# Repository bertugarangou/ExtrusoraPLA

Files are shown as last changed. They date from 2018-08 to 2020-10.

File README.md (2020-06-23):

# Extrusora PLA
Extrusora de plàstic PLA per produir filament reciclat per Impressores 3D.
Accés al projecte limitat. Veieu "[llicència](LICENSE.md)" o a través de [contacte](mailto:albertgarangou@gmail.com).

## Referències
* [Arduino](https://www.arduino.cc/) - Software
* [Arduino LiquidCrystal Library](https://www.arduino.cc/en/Reference/LiquidCrystal) - LLibreria d'Arduino per LCD.
* [Arduino Tasker Library](https://github.com/joysfera/arduino-tasker) - Llibreria d'Arduino per l'ús multi-tasca.
* Possiblament més referències poden ser incloses, en futur o actuals.

## Autors
* **Albert Garangou Culebras** - *Autor principal del projecte*

## Llicència
**Tots els drets reservats, Albert Garangou Culebras.**
Podeu trobar una còpia de la llicència a [LICENSE.md](LICENSE.md) i més detalls sobre el que és permés.

## Reconeixaments
* *Tutor del Treball de Recerca* - **Jordi Fanals Oriol**

## Contacte
Podeu contactar al correu [albertgarangou@gmail.com](mailto:albertgarangou@gmail.com).
També per missetjaria de Github si teniu un perfil.

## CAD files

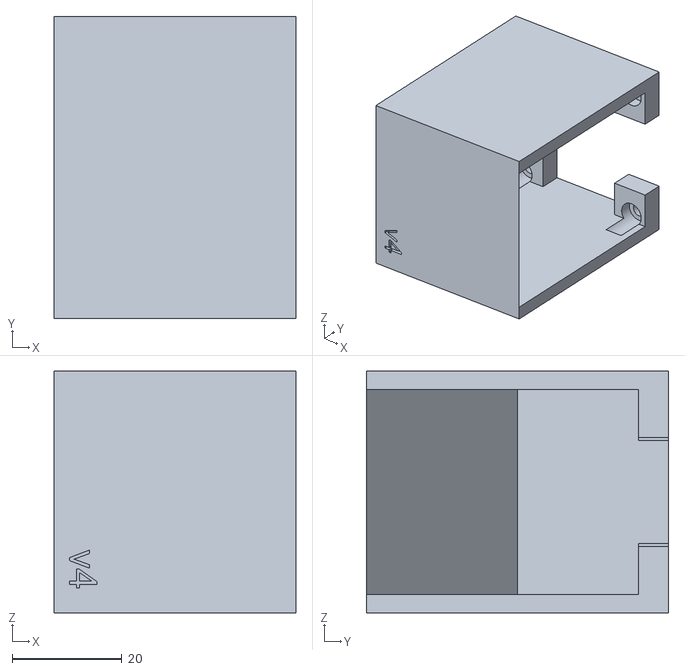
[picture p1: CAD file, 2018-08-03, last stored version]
Parts3D/Parts_STL_per_imprimir/Cos Refrigerador v4.stl
44.0 x 55.0 x 44.0

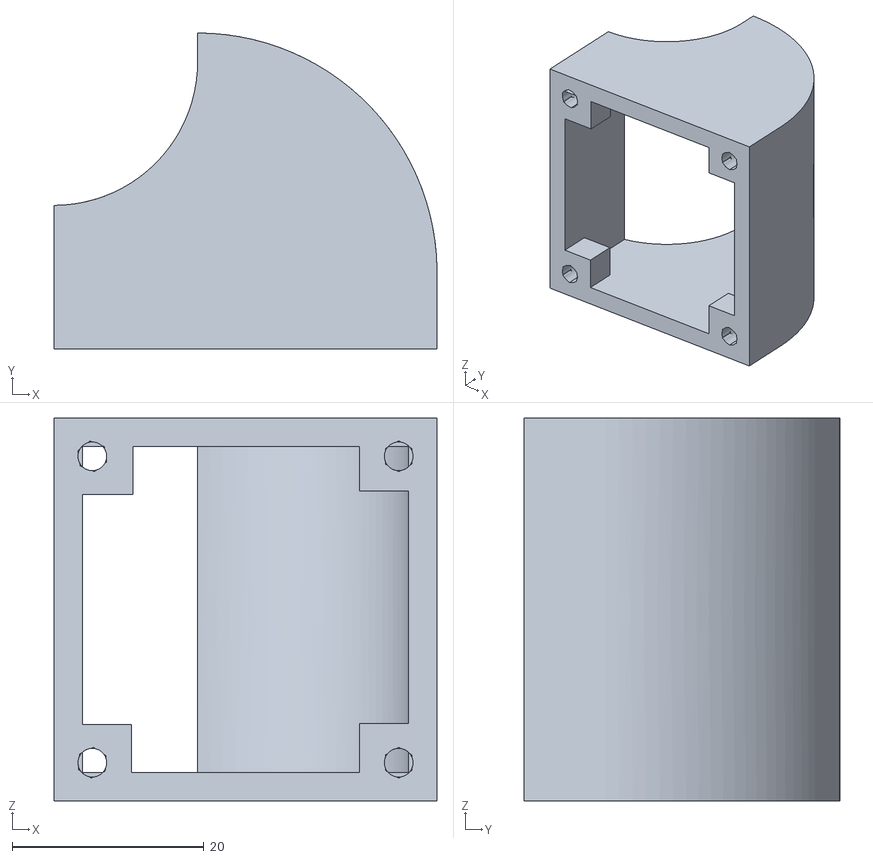
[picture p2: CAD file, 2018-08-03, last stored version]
Parts3D/Parts_STL_per_imprimir/Boca Refrigerador v2.stl
40.0 x 33.0 x 40.0

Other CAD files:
Esquemes/Ensamblatge Broca-Eix motor.dwg
Parts/Esquemes/0. Base/Estructura base.dwg
Parts/Esquemes/1. Extrusora/suport motor-1.dwg
Esquemes/suport motor-1.dwg
Parts/Esquemes/1. Extrusora/tremuja.ipt
Parts/Models/0. Base/Estructura base.ipt
Parts/Models/1. Ventiladors/Ventilador bobina - boca.ipt
Parts/Models/1. Ventiladors/Ventilador bobina - suport.ipt
Parts/Models/1. Ventiladors/Ventilador controladores - boca.ipt
Parts/Models/1. Ventiladors/Ventilador controladores - suport.ipt
Parts/Models/1. Ventiladors/Ventilador filament - boca.ipt
Parts/Models/1. Ventiladors/Ventilador filament - cosPETIT.ipt
Parts/Models/1. Ventiladors/Ventilador tub - cos.ipt
Parts/Models/1. Ventiladors/Ventilador tub - guies.ipt
Parts/Models/1. Ventiladors/ventilador emergència inferior.ipt
Parts/Models/1. Ventiladors/ventilador emergència superior.ipt
Parts/Models/2. Extrusora/Motor extrusora - suport.ipt
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

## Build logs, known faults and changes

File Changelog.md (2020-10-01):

# Historial de versions

### Com funciona:
### Versió [NUMERO] (Data) - *CodeName*
 ### <No Funcional>

 #### Millores

  * Descripció
  * Descripció
      * Contingut

 #### Correccions
  * Descripció

 #### Errors coneguts
  * Descripció

 #### Més informació
  * "Commits"

---
---
---

## Versió 1 (15/10/2018) - *Inicial*

 ### Errors coneguts
  * El sensor IR detecta el fil per cualpa d'alguns llums d'habitacions. 
---
## Versió 1.1 (16/10/2018)
 ### Millores
  * El sensor IR detecta correctament el filament amb un protector.
 ---
 ## Versió 1.2 (22/11/2018)
  ### Millores
   * Adaptació per entrega TdR
 ---
  ## Versió 1.3 (12/02/2019)
   ### Millores
   * Rectificació llicència
 ---
  ## Versió 1.3.1 (01/06/2019)
   ### Canvis
   * Restrinció de l'accés al projecte amb efecte retroactiu. Ja no es permet l'accés públic, només sota demanda.
 ---
  ## Versió 1.3.1 (01/10/2020)
   ### Canvis
   * Modificació de l'estructura de llicència i usos del projecte per arxivar-lo indefinidament.

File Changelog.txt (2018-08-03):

# Historial de versions

### Com funciona?

 ## Versió [NUMERO] - *CodeName*
 
  * Canvi 1
  * Canvi 2
  * ...

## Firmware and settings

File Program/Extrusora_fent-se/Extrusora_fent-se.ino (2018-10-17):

/*
  Extrusora de PLA controlada per Arduino Mega 2560.

  Projecte:
  - https://github.com/bertugarangou/ExtrusoraPLA
  - Extrusora feta per Albert Garangou,
    com a Treball de Recerca a 2n de Batxillerat,
    curs 2018/2019, tutor: Jordi Fanals Oriol,
    codi amb Arduino IDE.
  - Tots els drets reservats 2019 Albert Garangou Culebras (albertgarangou@gmail.com).
    Aquest codi està llicenciat amb base a la Creative "Commons Attribution-NonCommercial-NoDerivatives 4.0 International License".
    Altres regles i mesures pròpies sobreescriuen i modifiquen aquesta llicència són presents, consulta el web origen per a més informació.

*/
/*+++++++++++++Llibreries++++++++++++++*/
#include <max6675.h>
MAX6675 tempSensorResistors(11, 12, 13);
MAX6675 tempSensorEnd(8, 9, 10);

#include <Wire.h>

#include <LiquidCrystal_I2C.h>
LiquidCrystal_I2C lcd(0x27, 16, 2); //PINS SDA i SCL lcd

/*+++++++++++++Llibreries++++++++++++++*/
/*++Declaració variables i constants+++*/
int const lcdUpdateFrequency = 250;  //1000-1500-x
int const tempReaderFrequency = 1000; //1000-1500-x
int const heaterFrequency = 0; //0 (instantari)-500-1000-x

int const INTFanFil = 6;
int const INTFanTube = 7;
int const relayFanFil = 52;
int const relayFanTube = 50;
int const STOPBtn = 30;
int const brunzidor = 51;
int const extruderStep = 25;
int const extruderDir = 26;
int const extruderEn = 28;
int const coilStep = 24;
int const coilDir = 27;
int const coilEn = 29;
int const filamentDetector = 36;
int const INTHeat = 53;
int const INTExtruder = 2;
int const INTExtruderRev = 3;
int const INTCoil = 4;
int const INTCoilRev = 5;
int const INTHeater = 49;
int const relayResistors = 32;

bool error = false;
bool canExtrude = false;
bool canCoil = false;

bool extrudingFwd = false;
bool extrudingRev = false;
bool coilingFwd = false;
bool coilingRev = false;

bool heatingPause = false;
bool heating = false;

bool canCoilByFilamentDetector = false;

int tempToShow;
float tempRest = 0.0;
float currentTempResistors = 0.0;
float currentTempEnd = 0.0;

float desiredTemp;
float desiredTempEnd;
float desiredTempResistors;

float tempResistors1 = 0.0;
float tempResistors2 = 0.0;
float tempResistors3 = 0.0;
float tempEnd1 = 0.0;
float tempEnd2 = 0.0;
float tempEnd3 = 0.0;
float finalTempEnd = 0.0;
float finalTempResistors = 0.0;

int const slowTempRange = 5;  

int tempResistorsRest;
int tempEndRest;

unsigned long ultimMillis_LCDMain = 0UL;
unsigned long ultimMillis_extruderStart = 0UL;
unsigned long ultimMillis_extruderStop = 0UL;
unsigned long ultimMillis_coilStart = 0UL;
unsigned long ultimMillis_coilStop = 0UL;
unsigned long ultimMillis_tempReader = 0UL;
unsigned long ultimMillis_heaterMain = 0UL;

int const extruderNEINSpeed = 6;
int const coilNEINSpeed = 20;

byte downArrow[8] = {
  B00100,
  B00100,
  B00100,
  B00100,
  B00100,
  B10101,
  B01110,
  B00100
};

byte upArrow[8] = {
  B00100,
  B01110,
  B10101,
  B00100,
  B00100,
  B00100,
  B00100,
  B00100
};

byte cross[8] = {
  B00000,
  B10001,
  B01010,
  B00100,
  B01010,
  B10001,
  B00000,
  B00000
};

byte check[8] = {
  B00000,
  B00000,
  B00001,
  B00010,
  B10100,
  B01000,
  B00000,
  B00000
};

byte rev[8] = {
  B00010,
  B00110,
  B01110,
  B11110,
  B01110,
  B00110,
  B00010,
  B00000
};

byte pause[8] = {
  B00000,
  B01010,
  B01010,
  B01010,
  B01010,
  B01010,
  B00000,
  B00000
};

/*++Declaració variables i constants+++*/
/*+++++++++++Declaracio funcions+++++++++++*/
void lcdController();
void fansController();
void extruderController();
void coilController();
void filamentDetectorFunction();
void heater();
void tempRead();
void errorProcedure();
void quickTempRead();
/*+++++++++++Declaracio funcions+++++++++++*/

void setup(){
  Serial.begin(9600); //inicia la depuració
  lcd.init();
  lcd.backlight();
  lcd.createChar(1, downArrow);
  lcd.createChar(2, upArrow);
  lcd.createChar(3, cross);
  lcd.createChar(4, check);
  lcd.createChar(5, rev);
  lcd.createChar(6, pause);
  
  lcd.clear();
  pinMode(INTFanFil, INPUT);
  pinMode(INTFanTube, INPUT);
  pinMode(STOPBtn, INPUT);
  pinMode(relayFanFil, OUTPUT);
  pinMode(relayFanTube, OUTPUT);
  pinMode(brunzidor, OUTPUT);
  pinMode(extruderStep, OUTPUT);
  pinMode(extruderDir, OUTPUT);
  pinMode(extruderEn, OUTPUT);
  pinMode(coilStep, OUTPUT);
  pinMode(coilDir, OUTPUT);
  pinMode(coilEn, OUTPUT);
  pinMode(filamentDetector, INPUT);
  pinMode(INTExtruder, INPUT);
  pinMode(INTExtruderRev, INPUT);
  pinMode(INTCoil, INPUT);
  pinMode(INTCoilRev, INPUT);
  pinMode(INTHeater, INPUT);
  pinMode(relayResistors, OUTPUT);
  digitalWrite(relayResistors, LOW);
}

void loop(){
 if(digitalRead(STOPBtn) == 0 || error == true){
  digitalWrite(brunzidor, HIGH);
  Serial.println("*****************************************");
  Serial.print("*   STOP");
  Serial.println(", entrant en mode emergència!   *");
  Serial.println("*                                       *");
  Serial.println("* NO DESCONECTAR FINS QUE ESTIGUI FRED! *");
  Serial.println("*****************************************");
  lcd.clear();
  lcd.print("!NO DESCONECTAR!");
  lcd.setCursor(9,1);
  lcd.print("ALERTA!");
  errorProcedure();
  while(true){//bucle infinit
  digitalWrite(brunzidor, LOW);
  lcd.noBacklight();
  quickTempRead();
  digitalWrite(brunzidor, HIGH);
  lcd.setCursor(0,1);
  lcd.print((int) finalTempResistors);
  lcd.print(char(223));
  lcd.print("/");
  lcd.print((int) finalTempEnd);
  lcd.print(char(223));
  lcd.backlight();
  delay(2000);
  }
 }
  else{ //funcionament estandart del programa (aka no hi ha cap error)
    lcdController();
    filamentDetectorFunction();
    fansController();
    tempRead();
    heater();
    extruderController();
    coilController();
    
  }
} //end

/*+++++++++++Definició funicons++++++++++++*/
void extruderController(){
  if (digitalRead(INTExtruder) == LOW && digitalRead(INTExtruderRev) == HIGH){//activat
    if(tempToShow > 169 && tempRest > -10){
      canCoil = true;
      if(millis() - ultimMillis_extruderStart >= extruderNEINSpeed){
        extrudingFwd = true;
        extrudingRev = false;
        digitalWrite(extruderStep, HIGH);
      if(millis() - ultimMillis_extruderStop >= extruderNEINSpeed){
        digitalWrite(extruderStep, LOW);
        ultimMillis_extruderStop = millis();
        ultimMillis_extruderStart = millis();
        }
      }
    }
  }
  else if(digitalRead(INTExtruder) == LOW && digitalRead(INTExtruderRev) == LOW){//invertit
    if(tempToShow > 169 && tempRest > -10){
      canCoil = false;
      if(millis() - ultimMillis_extruderStart >= extruderNEINSpeed){
        extrudingRev = true;
        extrudingFwd = false;
        digitalWrite(extruderDir, HIGH);
        digitalWrite(extruderStep, HIGH);
      if(millis() - ultimMillis_extruderStop >= extruderNEINSpeed){
        digitalWrite(extruderStep, LOW);
        digitalWrite(extruderDir, LOW);
        ultimMillis_extruderStop = millis();
        ultimMillis_extruderStart = millis();
        }
      }
    }
  }
  else{ //desactivat
    extrudingFwd = false;
    extrudingRev = false;
    canCoil = false;
  }
}

void coilController(){
  if (digitalRead(INTCoil) == LOW && digitalRead(INTCoilRev) == LOW){ // tots dos activats
    if(millis() - ultimMillis_coilStart >= coilNEINSpeed){
      coilingFwd = false;
      coilingRev = true;
      digitalWrite(coilStep, HIGH);
    if(millis() - ultimMillis_coilStop >= coilNEINSpeed){
      digitalWrite(coilStep, LOW);
      ultimMillis_coilStop = millis();
      ultimMillis_coilStart = millis();
      }
    }
  }
  else if(digitalRead(INTCoil) == LOW && digitalRead(INTCoilRev) == HIGH && canCoilByFilamentDetector == true){ // sense invertir direcció
    if(millis() - ultimMillis_coilStart >= coilNEINSpeed){
      coilingFwd = true;
      coilingRev = false;
      digitalWrite(coilDir, HIGH);
      digitalWrite(coilStep, HIGH);
      if(millis() - ultimMillis_coilStop >= coilNEINSpeed){
        digitalWrite(coilStep, LOW);
        digitalWrite(coilDir, LOW);
        ultimMillis_coilStop = millis();
        ultimMillis_coilStart = millis();
      }
    }
  }
  else{
    digitalWrite(coilStep, HIGH);
    coilingFwd = false;
    coilingRev = false;
  }
}

void fansController(){
  if(digitalRead(INTFanFil) == LOW){ //quan s'activa l'interruptor adequat
    digitalWrite(relayFanFil, LOW); //activar relé ventilador
    //Serial.println("Ventilador: Filament **ON**");
  }
  else{ //sinó
    digitalWrite(relayFanFil, HIGH); //desactiva'l
    //Serial.println("Ventilador: Filament **OFF**");
  }
    
  if(digitalRead(INTFanTube) == LOW){  //si s'activa l'interruptor adequat
    digitalWrite(relayFanTube, LOW);  //activa el relé del ventilador
    //Serial.println("Ventilador: Extrusora **ON**");
  }
  else{ //sinó
    digitalWrite(relayFanTube, HIGH);  //desactiva'l
    //Serial.println("Ventilador: Extrusora **OFF**");
  }
}

void lcdController(){
  if(millis() - ultimMillis_LCDMain >= lcdUpdateFrequency){
    lcd.setCursor(0,0);
    lcd.print((int) tempToShow);
    lcd.print("/");
    lcd.print((int) desiredTemp);
    lcd.print(char(223));
    lcd.print("  ");
      
    if(canExtrude == true){ //estat general
      lcd.setCursor(10,0);
      lcd.print("ACTIVAT");
    }
    else if(canExtrude == false && heating == true){
      lcd.setCursor(10,0);
      lcd.print("ESPERA");
    }
    else{
      lcd.setCursor(10, 0);
      lcd.print(" PAUSA");
    }

    if(extrudingFwd == true){ //estat extrusor
      lcd.setCursor(0,1);
      lcd.print("E:");
      lcd.write(4);
      lcd.print(" ");
    }
    else if(extrudingRev == true){
      lcd.setCursor(0,1);
      lcd.print("E:");
      lcd.write(5);
      lcd.write(5);
    }
    else{
      lcd.setCursor(0,1);
      lcd.print("E:");
      lcd.write(3);
      lcd.print(" ");
    }
    
    if(coilingFwd == true){  //estat bobina
      lcd.setCursor(11,1);
      lcd.print("B:");
      lcd.write(4);
      lcd.print(" ");
    }
    else if(coilingRev == true){
      lcd.setCursor(11,1);
      lcd.print("B:");
      lcd.write(5);
      lcd.write(5);
    }
     else{
      lcd.setCursor(11,1);
      lcd.print("B:");
      lcd.write(3);
      lcd.print(" ");
    }

    if(heating == true && heatingPause == false){  //estat heating
      lcd.setCursor(6,1);
      lcd.print("H:");
      lcd.write(4);
    }
    else if(heating == true && heatingPause == true){
      lcd.setCursor(6,1);
      lcd.print("H:");
      lcd.write(6);
    }
    else{
      lcd.setCursor(6,1);
      lcd.print("H:");
      lcd.write(3);
    }

    
      if(coilingFwd == true){
      lcd.setCursor(15,1);
      lcd.write(2);
      }
      else if(coilingRev == true){
      lcd.setCursor(15,1);
      lcd.write(1);
      }
    else{
      lcd.setCursor(15,1);
      lcd.print(" ");
      }
      
    ultimMillis_LCDMain = millis();
  }
}

void filamentDetectorFunction(){
  if(extrudingFwd == true){
    if(digitalRead(filamentDetector) == LOW){
      canCoilByFilamentDetector = true;
    }
    else{
      canCoilByFilamentDetector = false;
    }
  }
}

void heater(){
  if(digitalRead(INTHeater) == LOW){
    desiredTemp = 175;
    desiredTempResistors = 190;
    desiredTempEnd = 165;
    
    //if(millis() - ultimMillis_heaterMain >= heaterFrequency){
    tempRest = desiredTemp - tempToShow;
      if(tempToShow > 0 && tempRest > 1){  //escalfant de lluny
        digitalWrite(relayResistors, HIGH);
        heating = true;
        heatingPause = false;
      }
      else if(tempRest <= -2){  //massa alta
        digitalWrite(relayResistors, LOW);
        heating = true;
        heatingPause = true;
        digitalWrite(relayFanTube, LOW);
      }
      else if(tempToShow >0 && tempRest <= 1 && tempRest > -3){ // pausant temperatura està ok
        digitalWrite(relayResistors, LOW);
        heatingPause = true;
        heating = true;
      }
      else{ //no escalfa
        digitalWrite(relayResistors, LOW);
        heating = false;
        heatingPause = false;
      }
    //}
  }
  else if (digitalRead(INTHeater) == HIGH){
    desiredTempEnd = 0;
    desiredTempResistors = 0;
    desiredTemp = 0;
    digitalWrite(relayResistors, LOW);
    heating = false;
  }
}

void errorProcedure(){
  digitalWrite(relayFanFil, LOW);
  digitalWrite(relayFanTube, LOW);
  digitalWrite(extruderStep, HIGH);
  digitalWrite(coilStep, LOW);
  digitalWrite(relayResistors, LOW);
  //desiredTempAutoSetterVariableIDon'tKnowTheName = 0;
}

void quickTempRead(){
  tempEnd1 = tempSensorEnd.readCelsius();
  tempResistors1 = tempSensorResistors.readCelsius();
  delay(500);
  tempEnd2 = tempSensorEnd.readCelsius();
  tempResistors2 = tempSensorResistors.readCelsius();
  delay(500);
  tempEnd3 = tempSensorEnd.readCelsius();
  tempResistors3 = tempSensorResistors.readCelsius();
  finalTempEnd = (tempEnd1 + tempEnd2 + tempEnd3) / 3;
  finalTempResistors = (tempResistors1 + tempResistors2 + tempResistors3) / 3;
  
}

void tempRead(){
  if(millis() - ultimMillis_tempReader >= tempReaderFrequency){
    currentTempEnd = tempSensorEnd.readCelsius();
    currentTempResistors = tempSensorResistors.readCelsius();
    //Serial.println(currentTempEnd);
    //Serial.println(currentTempResistors);


    tempToShow = (currentTempEnd * 70 + currentTempResistors * 30) / 100;
    //Serial.println(tempToShow);
    //Serial.println("-------------");
    ultimMillis_tempReader = millis();
  }
  //heat suficient --> canExtrude = true
}
/*+++++++++++Definició funicons++++++++++++*/

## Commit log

2018-08-03 Uploaded 3D parts: old-acoplament, boca-refrigerador and cos-refrigerador
    [Boca Refrigerador v2.f3d, Boca Refrigerador v2.stl, Cos Refrigerador v4.f3d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]
2018-08-03 added 3d files and schemes
    [Boca Refrigerador v2.f3d, Boca Refrigerador v2.stl, Cos Refrigerador v4.f3d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]
2018-08-07 Added new 3d models and parts
    [Ensamblatge Broca-Eix motor.dwg, detector curvament fil.ipt, suport motor-1.dwg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]
2018-08-07 Added fritzing project
    [extruder.fzz]
2018-08-07 Updated fritzing comments
    [extruder.fzz]
2018-08-07 program moved to subfolder for direct use on Arduino IDE
2018-08-07 edited and reverted
    [extruder.fzz]
2018-08-07 Rewrote to use Stepper library
    No backward movement was done propperly so Arduino's library "Stepper" was added to do this frustrating painful little job
2018-08-07 Rewrote code to use stepper library
2018-08-08 Replaced L928n with tb6600
    [extruder.fzz]
2018-08-09 Added readTemp() function
    Added readTemp() which consists on reading the temp from a NTC, converting raw data to C and K degrees. It has benn used millis() to update those values to prevent stopping the entire code with delay()
    [Extrusora.ino]
2018-08-09 Don't know what has changed
    Scared to delete that...
    [extruder.fzz]
2018-08-13 added support for multiple fan switches
2018-08-13 improved Serial.print communications on switches
2018-08-13 added support for 2 motors and directional movement
2018-08-13 added missing comments 1/2
    [Extrusora.ino]
2018-08-13 see description for changes
    -replaced doStop() with automatic processes with checks
    -removed callerror() function (will be recovered later)
    -added heat procedures with PI (proportional and integrative)
    [Extrusora.ino]
2018-08-13 Added checks on heater's switch
2018-08-14 corrected diadoe polarization
    [extruder.fzz]
2018-08-14 Added lcd
    [extruder.fzz]
2018-08-17 Added up to date 3d parts
    [Bobinatge - eix bobina.ipt, Bobinatge - suport lateral.ipt, Bobinatge - suport motor.ipt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]
2018-08-18 updated 3d parts
    [Bobinatge - acoplament eix.ipt, Bobinatge - eix bobina.0011.ipt, Bobinatge - eix bobina.ipt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]
2018-08-18 support custom motor speed
2018-08-18 added new part
    [Caixa control - estructura.0020.ipt, Caixa control - estructura.ipt, Suport - pantalla i potenciometre.ipt]
2018-08-18 improved walls and fan holes
    [Suport - pantalla i potenciometre.ipt]
2018-08-19 various updates
    [Bobinatge - acoplament eix.ipt, Bobinatge - eix bobina.0011.ipt]
2018-08-19 improved coil axis radius
    [Bobinatge - eix bobina.ipt, Estructura base.0008.ipt]
2018-08-23 modified parts
    [Bobinatge - eix bobina.0013.ipt, Bobinatge - eix bobina.ipt, Ventilador controladores - suport.0008.ipt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]
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2018-08-23 updated with new power circuit
    [extruder.fzz]
2018-08-23 updated parts
    [Relé - columnes tapa.ipt, Relé - columnes.ipt, Suport - pantalla i potenciometre tapa.ipt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]
2018-08-27 updated power circuit
    [extruder.fzz]
2018-08-29 modified & added new parts
    [Bobinatge - eix bobina.0013.ipt, Caixa control - tapa.ipt, Detector fil - suport.ipt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]
2018-08-31 added new components
    [Caixa control - tapa.ipt, Pantalla - botó encoder.ipt, Pantalla - cos.ipt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]
2018-09-12 updated & added parts
    [Base auxiliar - encaix estructura.ipt, Base auxiliar - esquadra.ipt, Bobinatge - suport motor.ipt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]
2018-09-12 moved old parts into different folder
    [Bobinatge - acoplament eix.ipt, Ventilador filament - cos.ipt]
2018-09-22 added design
    [tremuja.dwg]
2018-09-22 solved incorrect route
    [extruder.fzz]
2018-09-22 added lcd i2c support
2018-09-30 added buzzer and power expander for lcd
    [extruder.fzz]
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2018-10-01 motors funcionals (ara si)
2018-10-01 actualització de velocitats dels motors
2018-10-01 neteja de codi per finalitzar els motors
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2018-10-03 lectura de temperatura funcional
2018-10-03 varies millores
    * sistema de seguretat millorat
    *nous caràcters de la pantalla (personalitzats) per indicar si el filament està sent bobinat o no
2018-10-03 valors d'actualització de pantalla i de lectura de temperatura reduits
2018-10-04 varies millores
    *nous caràcters per la lcd
    *arregalt els estats mostrats a la pantalla
    *sistema bàsic per escalfar
    *neteja de variables obsolertes
2018-10-04 llicència actualitzada amb les noves regles
2018-10-04 caràcters i sistema de senyal per l'escalfament funcionals
    [Bobinatge - eix bobina.ipt]
2018-10-04 correcció d'altura
    [Bobinatge - eix bobina.ipt]
2018-10-07 nou test per comprovar el relé d'estat sòlid sense perill delectrocució
2018-10-08 Revert "Update Program/Extrusora_fent-se/Extrusora_fent-se.ino"
    This reverts commit 7af50d72c9f8ea57fbfb48b0b4d528f124a5b9a6.
    [Extrusora_fent-se.ino]
2018-10-08 Revert "Revert "Update Program/Extrusora_fent-se/Extrusora_fent-se.ino""
    This reverts commit b195f3a1daab2889d0247883903246308dd127db.
    [Extrusora_fent-se.ino]
2018-10-09 reistències de calor funcionals
2018-10-10 solucionat un problema amb ek SSR que no permetia activar-lo
    [Extrusora_fent-se.ino]
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2018-10-17 Update Parts3D/Models/1. Ventiladors/Ventilador bobina - suport.ipt
    [Ventilador bobina - suport.ipt]
2018-10-17 * Directoris canviats * Nous arxius
    [Base auxiliar - encaix estructura.ipt, Base auxiliar - esquadra.ipt, Bobinatge - acoplament eix.ipt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]
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2018-10-18 Merge pull request #18 from bertugarangou/new-verison-branch
    * Directoris canviats
    [Base auxiliar - encaix estructura.ipt, Base auxiliar - esquadra.ipt, Bobinatge - acoplament eix.ipt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]
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2018-10-19 calibració de temperatures i resposta d'error en emergència
    [Extrusora.ino]
2018-10-21 circuit actualitzat
    [extruder.fzz]
2018-10-25 LLicències ok, comentaris afegits i motor amb funcionament normal
    [TB6600.sch]
2018-10-29 noves parts per un possible venitlador nou d'emergència
    [ventilador emergència inferior.ipt, ventilador emergència superior.ipt]
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2018-11-03 eliminates peces no utilitzades
    [Pantalla - encaix slider 180g.ipt, Pantalla - encaix slider 90g.ipt, Pantalla - tirado 90gr.ipt]
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2019-01-04 Actualització final de llicència
    Aquesta modificació és de caràcter retroactiu, els casos anteiors seran redirigits a aquesta versió
2019-06-01 actualització de privacitat
    Noves mesures de privacitat s'han afegit. L'accés és limitat i amb funció retroactiva.
    [Estructura base.dwg]
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
